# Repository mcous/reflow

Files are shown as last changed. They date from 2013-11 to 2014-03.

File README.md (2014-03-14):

# reflow

Heater controller with thermocouple feedback to control any AC heating appliance. It was originally developed to turn a toaster oven into a solder reflow oven, but it'll control anything that runs on AC and gets hot.

## hardware v0.1

The current board contains an AVR ATMega328P microcontroller, a Sharp S212S01 solid-state relay, and an Analog Devices AD8495 K-type thermocouple amplifier. It has a temperature precision of about 0.5 degrees C and is accurate to about +/- 2 degrees C. It also has start, stop, and mode buttons; a rotary encoder for temperature settings; and a four-digit seven-segment display for showing temperature in C or F. 

The schematic and PCB layout files were created in [KiCad](http://www.kicad-pcb.org) and live the in `pcb` directory.

## firmware v0.1.1

The current firmware has two basic modes: hit and hold. Hit mode takes the temperature up to the set point and then shuts off, while hold mode attempts to hold the temperature at the set-point by turning the heat on when the temperature is below the set point, and off when it's above. This is not PID. It can also display the temperature in either Celsius or Fahrenheit.

The firmware is written in C++ and compiled on OS X using the latest [CrossPack for AVR](http://www.obdev.at/products/crosspack/index.html) and lives in the `firmware` directory. It'll probably compile fine on Linux; no idea about Windows, though.

## operation

* To switch temperature units, hold the set wheel down (it's also a button) until you see an F after the temperature (Fahrenheit) or a number with a decimal point (Celsius)
* To switch modes between hit and hold, press and release the set wheel button; the display will show either "hit" or "hold" for whatever mode has been selected
* To select a set point, turn the set wheel until the display shows your desired temperature
* Press the start button to start heating; the red light will go out and the green light will illuminate
	* In hit mode, once the temperature is hit, the heating will stop and the green light will go out, replaced by the red light
	* In hold mode, the program will not stop unless you tell it to
* Press the stop button to stop heating; the green light will go out and the red light will illuminate
* Whenever the relay is closed (i.e. heat is on) the red LED labeled "HOT" will illuminate

## things this board has been used for

* reflow toaster oven (in hit mode)
* sous vide slow-cooker (in hold mode)

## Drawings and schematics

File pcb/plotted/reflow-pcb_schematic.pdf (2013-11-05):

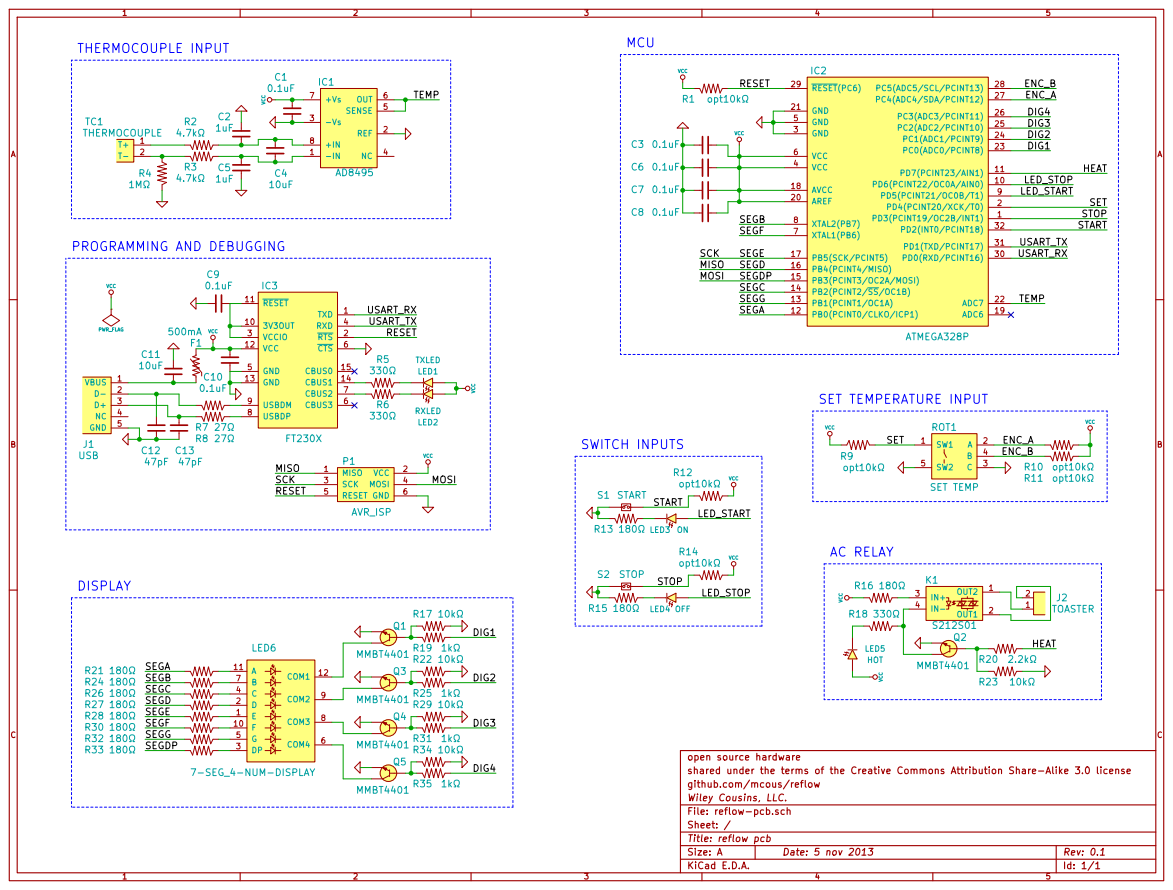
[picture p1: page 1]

LED_STOP
LED_START

MOSI VCC PROGRAMMING AND DEBUGGING

open source hardware
shared under the terms of the Creative Commons Attribution Share-Alike 3.0 license
github.com/mcous/reflow
Wiley Cousins, LLC.
File: reflow-pcb.sch
Sheet: /
Title: reflow pcb

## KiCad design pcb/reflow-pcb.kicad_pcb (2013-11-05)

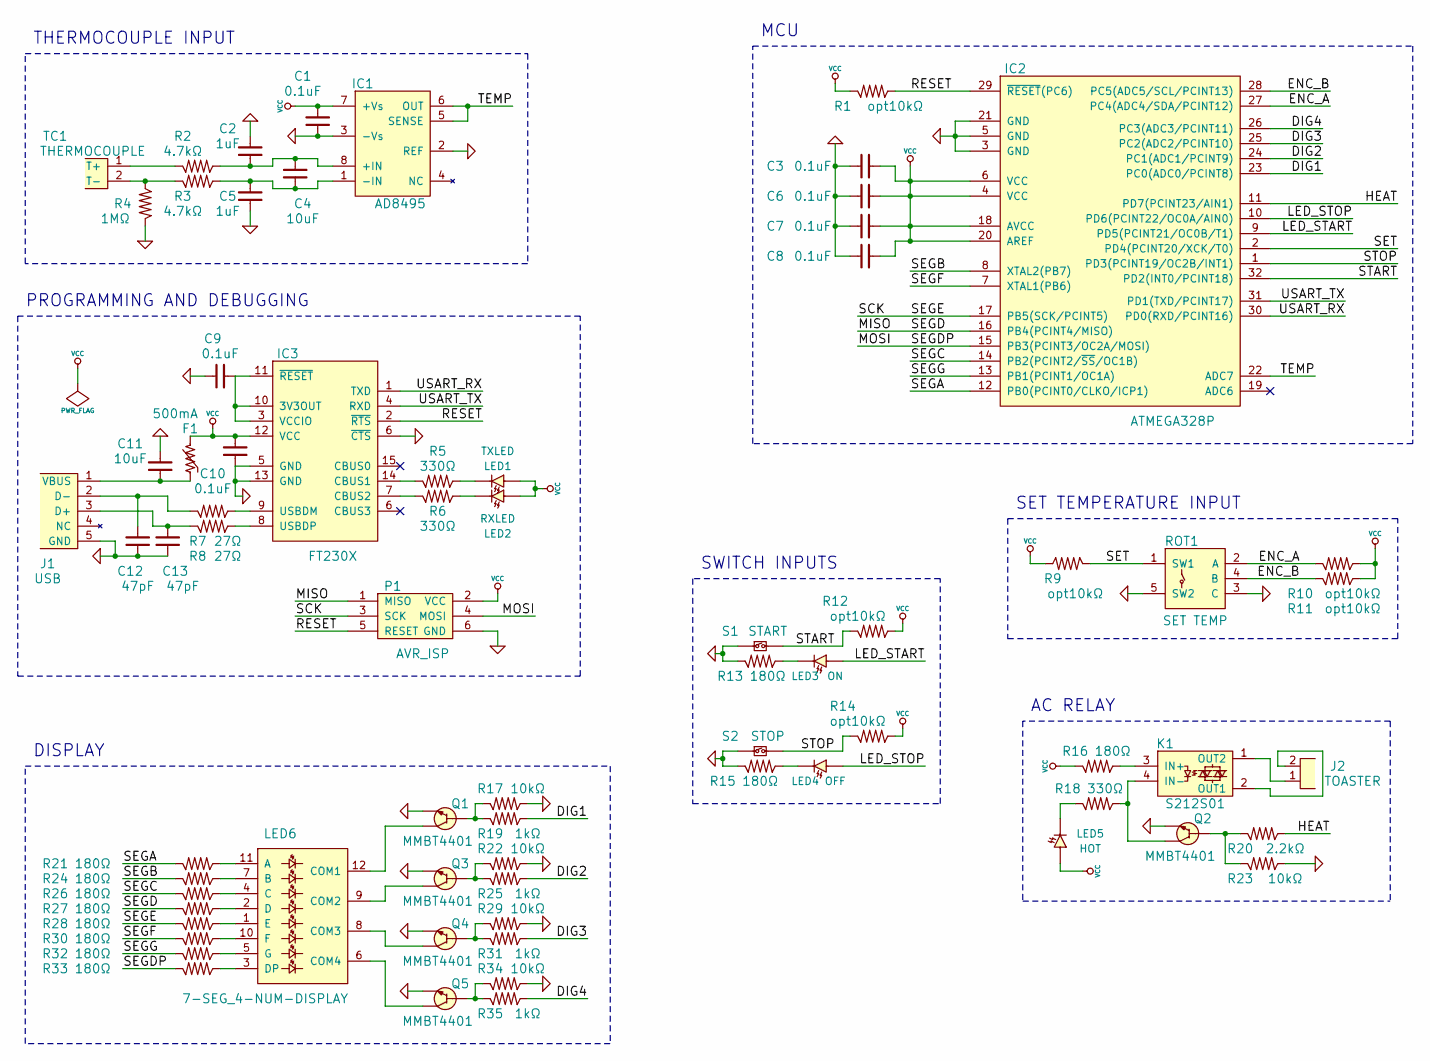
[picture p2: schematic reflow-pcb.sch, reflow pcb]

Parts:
C1, C3, C6, C7, C8, C9, C10: 0.1uF; 0603(1608m)
C2, C5: 1uF; 0603(1608m)
C4, C11: 10uF; 0603(1608m)
C12, C13: 47pF; 0603(1608m)
F1: 500mA; 1206(3216m); Part 0ZCJ0050FF2G
IC1: AD8495; MSOP8; Part AD8495ARMZ
IC2: ATMEGA328P; TQFP32_7mm; Part ATMEGA328P-AU
IC3: FT230X; SSOP16; Part FT230XS-R
J1: USB; MICROUSB_sm; Part 10118192-0001LF
J2: TOASTER; 2-PIN_SCREW-TERM_P200MIL; Part OSTTC022162
K1: S212S01; SHARP_SIP_SSR; Part S212S01F
LED1: TXLED; 0603(1608m)_led
LED2: RXLED; 0603(1608m)_led
LED3: ON; LED-5mm
LED4: OFF; LED-5mm
LED5: HOT; LED-5mm
LED6: 7-SEG_4-NUM-DISPLAY; SF_4-DIGIT_7-SEGMENT_CC; Part COM-11405
P1: AVR_ISP; 2x3-array
Q1, Q2, Q3, Q4, Q5: MMBT4401; SOT23; Part MMBT4401LT1G
R1, R9, R10, R11, R12, R14: opt10kΩ; 0603(1608m)
R2, R3: 4.7kΩ; 0603(1608m)
R4: 1MΩ; 0603(1608m)
R5, R6, R18: 330Ω; 0603(1608m)
R7, R8: 27Ω; 0603(1608m)
R13, R15, R16, R21, R24, R26, R27, R28, R30, R32, R33: 180Ω; 0603(1608m)
R17, R22, R23, R29, R34: 10kΩ; 0603(1608m)
R19, R25, R31, R35: 1kΩ; 0603(1608m)
R20: 2.2kΩ; 0603(1608m)
ROT1: SET TEMP; SF_ROTARY-ENCODER; Part RE130F-41-175F-12P
S1: START; SPST_4-pin-thru
S2: STOP; SPST_4-pin-thru
TC1: THERMOCOUPLE; THERMOCOUPLE_MINI_PCC-SMP; Part PCC-SMP-K

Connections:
/DIG1: IC2.23 (PC0(ADC0/PCINT8)), R19.2
/DIG2: IC2.24 (PC1(ADC1/PCINT9)), R25.2
/DIG3: IC2.25 (PC2(ADC2/PCINT10)), R31.2
/DIG4: IC2.26 (PC3(ADC3/PCINT11)), R35.2
/ENC_A: IC2.27 (PC4(ADC4/SDA/PCINT12)), R10.1, ROT1.2 (A)
/ENC_B: IC2.28 (PC5(ADC5/SCL/PCINT13)), R11.1, ROT1.4 (B)
/HEAT: IC2.11 (PD7(PCINT23/AIN1)), R20.2
/LED_START: IC2.9 (PD5(PCINT21/OC0B/T1)), LED3.2 (A)
/LED_STOP: IC2.10 (PD6(PCINT22/OC0A/AIN0)), LED4.2 (A)
/MISO: IC2.16 (PB4(PCINT4/MISO)), P1.1 (MISO), R27.1
/MOSI: IC2.15 (PB3(PCINT3/OC2A/MOSI)), P1.4 (MOSI), R33.1
/RESET: IC2.29 (~RESET~(PC6)), IC3.2 (~RTS~), P1.5 (RESET), R1.2
/SCK: IC2.17 (PB5(SCK/PCINT5)), P1.3 (SCK), R28.1
/SEGA: IC2.12 (PB0(PCINT0/CLKO/ICP1)), R21.1
/SEGB: IC2.8 (XTAL2(PB7)), R24.1
/SEGC: IC2.14 (PB2(PCINT2/~SS~/OC1B)), R26.1
/SEGF: IC2.7 (XTAL1(PB6)), R30.1
/SEGG: IC2.13 (PB1(PCINT1/OC1A)), R32.1
/SET: IC2.2 (PD4(PCINT20/XCK/T0)), R9.1, ROT1.1 (SW1)
/START: IC2.32 (PD2(INT0/PCINT18)), R12.1, S1.2
/STOP: IC2.1 (PD3(PCINT19/OC2B/INT1)), R14.1, S2.2
/TEMP: IC1.5 (SENSE), IC1.6 (OUT), IC2.22 (ADC7)
/USART_RX: IC2.30 (PD0(RXD/PCINT16)), IC3.1 (TXD)
/USART_TX: IC2.31 (PD1(TXD/PCINT17)), IC3.4 (RXD)
GND: C1.1, C2.2, C3.1, C5.1, C6.1, C7.1, C8.1, C9.1, C10.1, C11.2, C12.1, C13.1, IC1.2 (REF), IC1.3 (-Vs), IC2.3 (GND), IC2.5 (GND), IC2.21 (GND), IC3.5 (GND), IC3.6 (CBUS3), IC3.13 (GND), J1.5 (GND), P1.6 (GND), Q1.2 (E), Q2.2 (E), Q3.2 (E), Q4.2 (E), Q5.2 (E), R4.1, R13.1, R15.1, R17.2, R22.2, R23.2, R29.2, R34.2, ROT1.3 (C), ROT1.5 (SW2), S1.1, S2.1; also elsewhere on the board
unnamed: LED6.11 (A), R21.2
unnamed: LED3.1 (C), R13.2
unnamed: LED4.1 (C), R15.2
unnamed: LED6.7 (B), R24.2
unnamed: LED6.4 (C), R26.2
unnamed: LED6.2 (D), R27.2
unnamed: LED6.1 (E), R28.2
unnamed: LED6.10 (F), R30.2
unnamed: LED6.5 (G), R32.2
unnamed: LED6.3 (DP), R33.2
unnamed: Q1.1 (B), R17.1, R19.1
unnamed: K1.3 (IN+), R16.2
unnamed: Q4.1 (B), R29.1, R31.1
unnamed: Q5.1 (B), R34.1, R35.1
unnamed: LED6.12 (COM1), Q1.3 (C)
unnamed: LED6.9 (COM2), Q3.3 (C)
unnamed: Q3.1 (B), R22.1, R25.1
unnamed: IC3.14 (CBUS1), R5.1
unnamed: IC3.7 (CBUS2), R6.1
unnamed: LED2.1 (C), R6.2
unnamed: IC3.8 (USBDP), R8.2
unnamed: C13.2, J1.3 (D+), R8.1
unnamed: LED1.1 (C), R5.2
unnamed: R2.1, TC1.1 (T+)
unnamed: K1.4 (IN-), Q2.3 (C), R18.2
unnamed: IC3.9 (USBDM), R7.2
unnamed: C9.2, IC3.3 (VCCIO), IC3.10 (3V3OUT), IC3.11 (~RESET~)
unnamed: J2.2, K1.2 (OUT1)
unnamed: LED5.1 (C), R18.1
unnamed: J2.1, K1.1 (OUT2)
unnamed: C12.2, J1.2 (D-), R7.1
unnamed: Q2.1 (B), R20.1, R23.1
unnamed: LED6.8 (COM3), Q4.3 (C)
unnamed: LED6.6 (COM4), Q5.3 (C)
unnamed: C2.1, C4.2, IC1.8 (+IN), R2.2
unnamed: R3.1, R4.2, TC1.2 (T-)
unnamed: C4.1, C5.2, IC1.1 (-IN), R3.2
unnamed: C11.1, F1.1, J1.1 (VBUS)
VCC: C1.2, C3.2, C6.2, C7.2, C8.2, C10.2, F1.2, IC1.7 (+Vs), IC2.4 (VCC), IC2.6 (VCC), IC2.18 (AVCC), IC2.20 (AREF), IC3.12 (VCC), LED1.2 (A), LED2.2 (A), LED5.2 (A), P1.2 (VCC), R1.1, R9.2, R10.2, R11.2, R12.2, R14.2, R16.1

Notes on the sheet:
SWITCH INPUTS
SET TEMPERATURE INPUT
DISPLAY
AC RELAY
THERMOCOUPLE INPUT
PROGRAMMING AND DEBUGGING
MCU

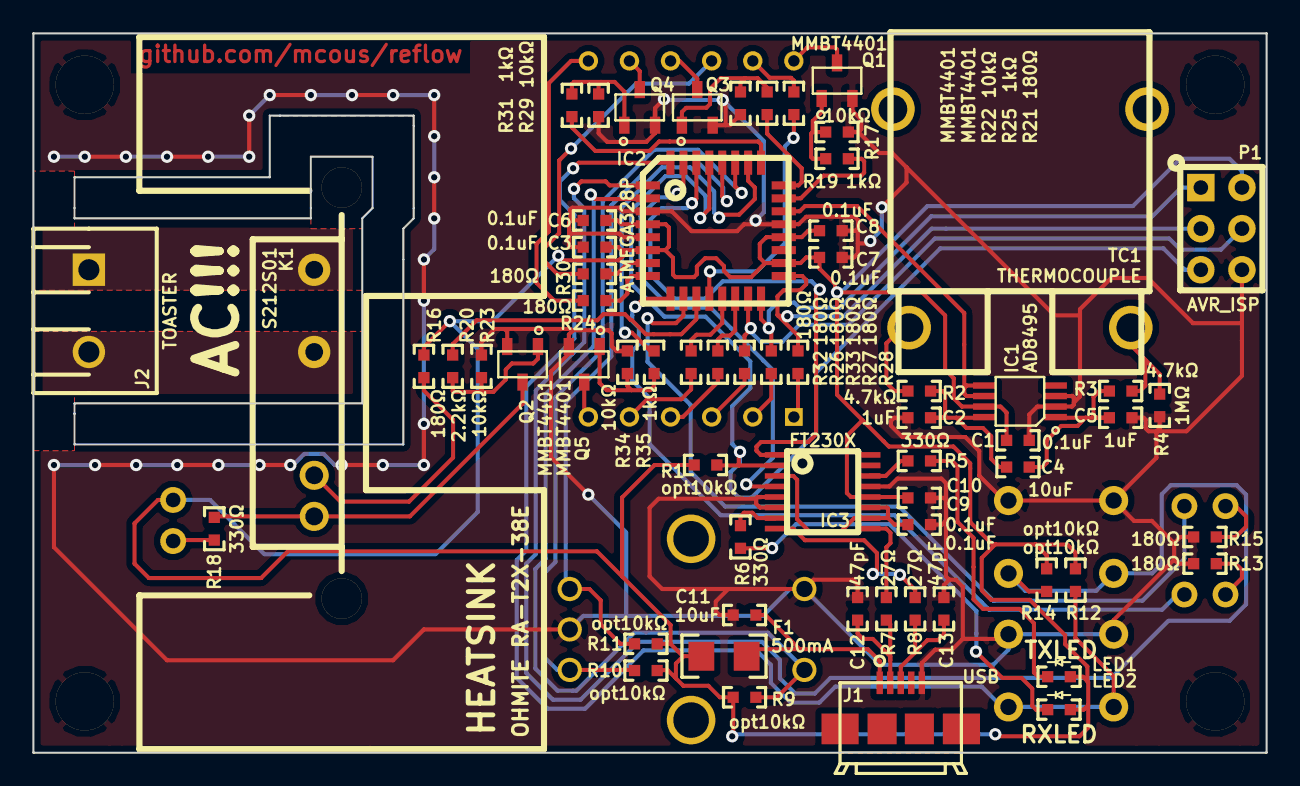
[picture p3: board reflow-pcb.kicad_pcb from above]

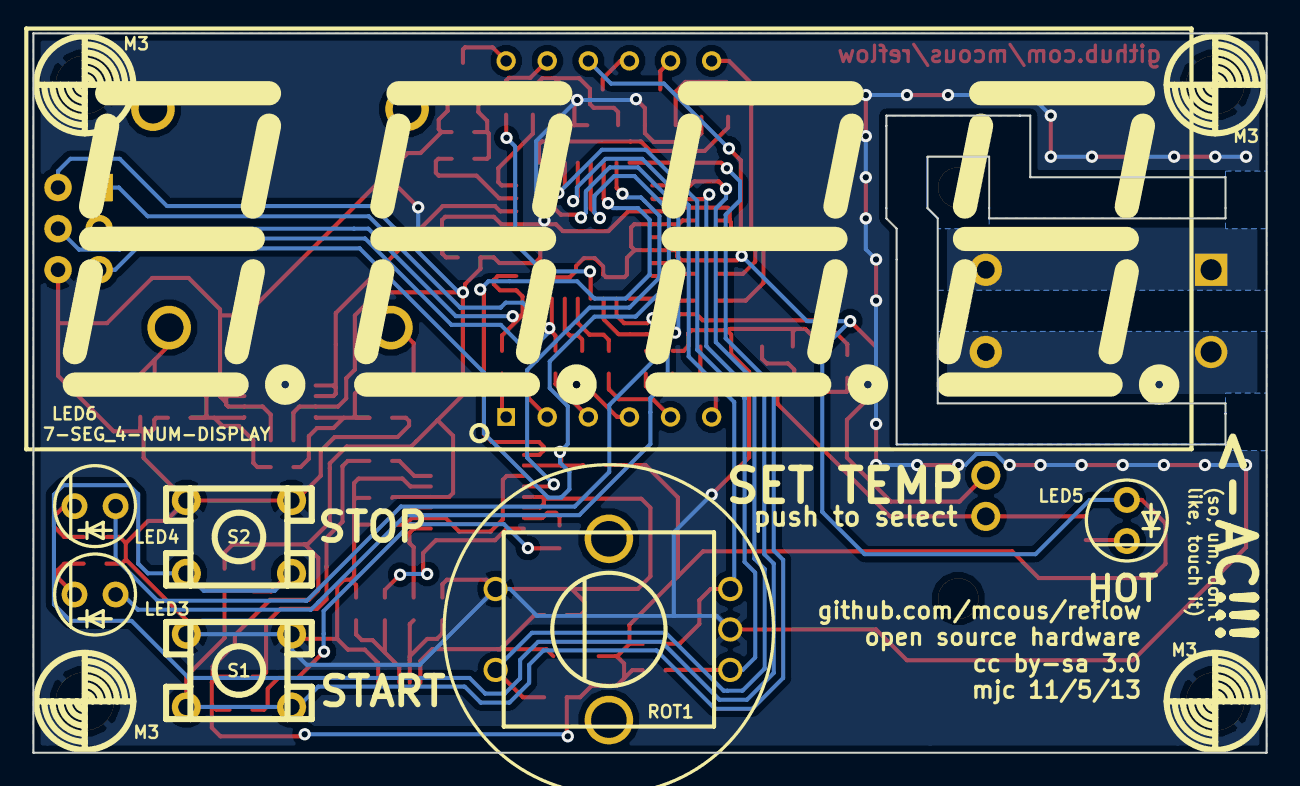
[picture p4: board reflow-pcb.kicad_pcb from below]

Board: 2 copper layers, 76.2 x 44.5 mm, 75 parts (11 on the bottom side), 64 nets.

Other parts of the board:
M3, M3#2, M3#3, M3#4: VAL**; M3

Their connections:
GND: M3.1, M3#2.1, M3#3.1, M3#4.1; also elsewhere on the board

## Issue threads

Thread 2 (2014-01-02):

FTDI RTS signal should go through a capacitor

mcous, 2014-01-02:
RTS line should go through a capacitor to pulse rather than hold AVR reset line.

Closed 2021-04-23.

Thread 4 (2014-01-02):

Need an LDO onboard for a proper AREF

mcous, 2014-01-02:
5V from USB is not an appropriate analog reference voltage as it is not going to be 5V at AREF and there's not a really robust way of measuring it short of using a volt meter and hard-coding the value into the firmware. That's kinda iffy, though. Put a 3.3V LDO on board and everyone's happy.

Closed 2021-04-23.

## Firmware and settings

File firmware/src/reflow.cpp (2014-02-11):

// reflow
// Copyright 2013 by Wiley Cousins, LLC.
// shared under the terms of the MIT License
//
// file: reflow.cpp
// description: application file for the reflow oven controller

#include <avr/io.h>
#include <avr/interrupt.h>
#include <util/atomic.h>
#include <util/delay.h>

#include "reflow.h"
#include "display.h"
#include "buttons.h"
#include "celsius.h"

// macro for event checking
#define event(T, M) ((T & M) == M)

// pin change ISR for rotary encoder
ISR(ENCODER_PCINT_vect) {
  e.handleChange();
}

// applicaiton event timer
ISR(REFLOW_EVENT_vect) {
  // set the flags
  // display refresh
  if (event(eventTimer, REFLOW_DISPLAY_EVENT)) {
    eventFlags |= REFLOW_DISPLAY_FLAG;
  }
  // button polling
  if (event(eventTimer, REFLOW_BUTTON_EVENT)) {
    eventFlags |= REFLOW_BUTTON_FLAG; 
  }
  // encoder reading
  if (event(eventTimer, REFLOW_ENCODER_EVENT)) {
    eventFlags |= REFLOW_ENCODER_FLAG;
  }
  // temperature reading
  if (event(eventTimer, REFLOW_THERMO_EVENT)) {
    eventFlags |= REFLOW_THERMO_FLAG;
  }

  // increment the counter and overflow if necessary
  eventTimer = (eventTimer < REFLOW_EVENT_MAX) ? eventTimer+1 : 0; 
}

// application main method
int main(void) {
  // disable global interrupts for setting stuff
  cli();

  // ISR volatiles
  // should already be 0 but hey safety first
  adcRead = 0;
  eventTimer = 0;
  eventFlags = 0;

  // get the display ready
  Display disp;
  disp.init();
  // get the buttons and encoder input ready
  Buttons b;
  b.init();
  e.init();
  uint8_t encoderCount = MODE_SET_DISPLAY_COUNT;
  uint8_t buttonCount  = MODE_SET_MODE_COUNT;
  // initialize the indicator LEDs
  initLeds();

  // temperature
  initThermo();
  bool targetHit = false;
  Celsius temp;
  Celsius target;
  target.set(200);
  uint8_t tempUnits = TEMP_UNIT_C;

  // text buffer for temperature display
  char d[7];
  uint8_t dLen = temp.toString(d);
  char s[7];
  uint8_t sLen = target.toString(s);

  // operating mode
  uint8_t mode = MODE_OFF | MODE_HIT;
  LED_PORT = (LED_PORT & ~LED_MASK) | LED_STOP;

  // enable the event timer
  enableEventTimer();

  // enable global interrupts
  sei();

  // sideways eight loop
  for (;;) {
    // take care of any events
    // display refresh
    if (eventFlags & REFLOW_DISPLAY_FLAG) {
      // refresh that shit yo
      disp.refresh();
      // clear the flag
      eventFlags &= ~REFLOW_DISPLAY_FLAG;
    }
    // button polling
    if (eventFlags & REFLOW_BUTTON_FLAG) {
      // poll that shit yo
      b.handleTimer();
      // handle buttons
      uint8_t buttons;
      //  button presses
      if (b.getHold(&buttons)) {
        // if set switch is held, switch units
        if (buttons == BUTTON_SET) {
          tempUnits ^= TEMP_UNIT_F;
        } 
      }
      else if (b.getPress(&buttons)) {
        if (buttons == BUTTON_START) {
          mode |= MODE_ON;
          targetHit = false;
        }
        else if (buttons == BUTTON_STOP) {
          mode &= ~MODE_ON;
          HEAT_PORT &= ~HEAT_PIN;
        }
        else if (buttons == BUTTON_SET) {
          buttonCount = 0;
          mode ^= (MODE_HIT | MODE_HOLD);
        }
      }
      // increment counter
      if (buttonCount < MODE_SET_MODE_COUNT) {
        buttonCount++;
      }
      // clear the flag
      eventFlags &= ~REFLOW_BUTTON_FLAG;
    }
    // encoder reading
    if (eventFlags & REFLOW_ENCODER_FLAG) {
      // read that shit yo
      int8_t enc = e.getChange();
      if (enc) {
        encoderCount=0;
        // change target based on encoder speed
        // slower = less increments
        if (enc == -1) {
          target--;
          target--;
        }
        else if (enc == 1) {
          target++;
          target++;
        }
        else if (enc == -2) {
          target -= 1;
        }
        else if (enc == 2) {
          target += 1;
        }
        else if (enc == -3) {
          target -= 10;
        }
        else if (enc == 3) {
          target += 10;
        }
        else if (enc < 0) {
          target -= 20;
        }
        else {
          target += 20;
        }
        // underflow protection
        if (target < 0) {
          target.set(0);
        }
        sLen = target.toString(tempUnits, s);
      }
      // increment counter
      if (encoderCount < MODE_SET_DISPLAY_COUNT) {
        encoderCount++;
      }
      // clear the flag
      eventFlags &= ~REFLOW_ENCODER_FLAG;
    }
    // thermometer reading
    if (eventFlags & REFLOW_THERMO_FLAG) {
      // measure that shit yo
      // take 4 ADC samples and divide by 2 to oversample to 11-bit precision
      // then, convert 11-bit number to 4x degrees C
      // steps combined for efficiency
      uint32_t c = 0;
      for (uint8_t i=4; i>0; i--) {
        // start an ADC conversion
        ADCSRA |= (1<<ADSC);
        // wait for conversion to complete
        while (ADCSRA & (1<<ADSC));
        c += ( ADCL | (ADCH << 8) );
      }
      c *= 25 * VREF;
      c >>= 7;
      temp.setScaled((int16_t)(c), TEMP_POWER);
      dLen = temp.toString(tempUnits, d);
      // clear the flag
      eventFlags &= ~REFLOW_THERMO_FLAG;
    }

    

    // check for open thermocouple
    if (temp > 500) {
      // write error flag
      mode |= MODE_ERR;
    }
    // else thermo data is good
    else {
      // clear error flag
      mode &= ~MODE_ERR;
      // check if we're displaying the set temp
      if (encoderCount < MODE_SET_DISPLAY_COUNT) {
        mode |= MODE_SET;
      }
      else if (buttonCount < MODE_SET_MODE_COUNT) {
        mode |= MODE_SHOW;
      }
      else {
        mode &= ~(MODE_SET | MODE_SHOW);
        if (mode & MODE_ON) {
          if (temp < target) {
            HEAT_PORT |= HEAT_PIN;
          }
          else {
            HEAT_PORT &= ~HEAT_PIN;
            if (mode & MODE_HIT) {
              mode &= ~MODE_ON;
              targetHit = true;
            }
          }
        }
      }
    }

    // set the display and status LEDs
    if (mode & MODE_ON) {
      LED_PORT = (LED_PORT & ~LED_MASK) | LED_START;
    }
    else {
      LED_PORT = (LED_PORT & ~LED_MASK) | LED_STOP;
    }
    // error is first priority, then set, then value
    if (mode & MODE_ERR) {
      char e[5] = {'e', 'r', 'r', '0', '\0'};
      disp.set(e, 4);
    }
    else if (mode & MODE_SET) {
      disp.set(s, sLen);
    }
    else if (mode & MODE_SHOW) {
      if (mode & MODE_HIT) {
        char e[4] = {'h', 'i', 't', '\0'};
        disp.set(e, 3); 
      }
      else {
        char e[5] = {'h', 'o', 'l', 'd', '\0'};
        disp.set(e, 4); 
      }
    }
    else {
      disp.set(d, dLen);
    }
  }

  // DEEP THOUGHT
  return 42;
}

// event timer
void enableEventTimer(void) {
  // enable timer 1 to fire at 512Hz
  // CTC mode, no prescaler, OCR1A = 15625
  TCCR1A = 0;
  TCCR1B = ( (1<<WGM12) | (1<<CS10) );
  TCCR1C = 0;
  OCR1A = 15625;
  // enable the compare interrupt
  TIMSK1 = (1<<OCIE1A);
}

void initLeds(void) {
  // set pins as outputs
  DDR(LED_PORT) |= LED_MASK;
  // set pins to low (off)
  LED_PORT &= ~LED_MASK;
}

void initHeat(void) {
  // set heater to output
  DDR(HEAT_PORT) |= HEAT_PIN;
  // set low (off)
  HEAT_PORT &= ~HEAT_PIN;
}

// intialize thermocouple reading
void initThermo(void) {
  // set up ADC on ADC7 with VREF as the reference voltage
  ADMUX = 7;
  // slow things down to 8 MHz / 64 = 125 kHz
  ADCSRA = ( (1<<ADPS2) | (1<<ADPS1) );
  // enable ADC, do a reading, and toss it
  ADCSRA |= ( (1<<ADEN) | (1<<ADSC) );
  // wait for conversion to complete
  while (ADCSRA & (1<<ADSC));
  // read the value;
  uint16_t read = ADCL | (ADCH << 8);
  (void) read;
}

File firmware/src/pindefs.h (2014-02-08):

// reflow
// Copyright 2013 by Wiley Cousins, LLC.
// shared under the terms of the MIT License
//
// file: pindefs.h
// description: pin definitions file for the reflow oven controller

#ifndef REFLOW_PINDEFS_H
#define REFLOW_PINDEFS_H

// include for AVR register addresses and interrupt vectors
#include <avr/io.h>

// DDR and PIN from port register macros
#define DDR(port) (*(&port-1))
#define PIN(port) (*(&port-2))

// display ports
#define DISPLAY_DIG_PORT  PORTC
#define DISPLAY_DIG_MASK  0x0F
#define DISPLAY_SEG_PORT  PORTB
#define DISPLAY_SEG_MASK  0xFF
// display segment pins
#define DISPLAY_SEG_A   (1<<0)
#define DISPLAY_SEG_B   (1<<7)
#define DISPLAY_SEG_C   (1<<2)
#define DISPLAY_SEG_D   (1<<4)
#define DISPLAY_SEG_E   (1<<5)
#define DISPLAY_SEG_F   (1<<6)
#define DISPLAY_SEG_G   (1<<1)
#define DISPLAY_SEG_DP  (1<<3)

// pushbutton port
#define BUTTON_PORT   PORTD
#define BUTTON_SET    (1<<4)
#define BUTTON_START  (1<<2)
#define BUTTON_STOP   (1<<3)
#define BUTTON_MASK   ( BUTTON_STOP | BUTTON_START | BUTTON_SET )
// pushbutton polling / debounce timer
#define BUTTON_TIMER_OVF_vect  TIMER2_OVF_vect

// encoder port
#define ENCODER_PORT   PORTC
#define ENCODER_A      (1<<4)
#define ENCODER_B      (1<<5)
#define ENCODER_MASK   ( ENCODER_B | ENCODER_A )
#define ENCODER_SHIFT  4
// encoder pin change
#define ENCODER_PCIE        (1<<PCIE1)
#define ENCODER_PCMSK       PCMSK1
#define ENCODER_PCINT_vect  PCINT1_vect

// mode indicator LEDs
#define LED_PORT   PORTD
#define LED_STOP   (1<<6)
#define LED_START  (1<<5)
#define LED_MASK   (LED_START | LED_STOP)

// heater
#define HEAT_PORT  PORTD
#define HEAT_PIN   (1<<7)

// temperature reading
#define TEMP_ADC  (1<<7)

#endif

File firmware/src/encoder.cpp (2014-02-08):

// reflow
// Copyright 2013 by Wiley Cousins, LLC.
// shared under the terms of the MIT License
//
// file: encoder.cpp
// description: class for rotary encoder input

#include "encoder.h"
#include "pindefs.h"

// contructor
Encoder::Encoder(void) {
  loc = 0;
  tick = 0;
  state = 0;
}

// encoder transition lookup table
const int8_t Encoder::trans[] PROGMEM = {
  0, 1, -1, 0, -1, 0, 0, 1, 1, 0, 0, -1, 0, -1, 1, 0
};

// initialization of pins and interrupts
void Encoder::init(void) {
  initPins();
  state = getState();
  initInt();
}
 
// handle the pin change interrupt (preferably with aplomb) 
void Encoder::handleChange(void) {
  // shift the previous state over and pull in the new state
  state = (((state<<2) | getState()) & 0x0F);
  // increment or decrement the location with the lookup table
  tick += pgm_read_byte(&(trans[state]));
  if (tick > 3) {
    tick = 0;
    loc++;
  }
  else if (tick < -3) {
    tick = 0;
    loc--;
  }
}

// get rotation since last check
// clockwise = positive, counter-clockwise = negative
int8_t Encoder::getChange(void) {
  int8_t ret = loc;
  loc = 0;
  return ret;
}

// get encoder state
// returns 0000 00AB
uint8_t Encoder::getState(void) {
  // mask the encoder pins and shift for processing
  return ((PIN(ENCODER_PORT) & ENCODER_MASK) >> ENCODER_SHIFT);
}

// initialize pins and pullups
void Encoder::initPins(void) {
  // set pins to input
  DDR(ENCODER_PORT) &= ~ENCODER_MASK;
  // enable pullups
  ENCODER_PORT |= ENCODER_MASK;
}

// initialize pin change interrupts
void Encoder::initInt(void) {
  // set up pin change interrupt on the pins
  ENCODER_PCMSK |= ENCODER_MASK;
  // enable the interrupt
  PCICR |= ENCODER_PCIE;
}

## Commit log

2013-11-02 starting kicad project
2013-11-02 starting schematic
    [relow-pcb.sch]
2013-11-03 thermocouple circuit set up
    [relow-pcb.sch]
2013-11-03 realy circuit done
    [relow-pcb.sch]
2013-11-03 added rotary encoder
    [relow-pcb.sch]
2013-11-03 going to bed
2013-11-03 added a display
    [relow-pcb.sch]
2013-11-03 initial pass at schematic done
    [relow-pcb.sch]
2013-11-04 I lied. Adding a FTDI USB to USART
    [relow-pcb.sch]
2013-11-04 might actually be done with this schematic
    [relow-pcb.sch]
2013-11-04 footprint assignment almost done. going to bed
    [relow-pcb.sch]
2013-11-05 working on the board
    [relow-pcb.kicad_pcb, relow-pcb.sch]
2013-11-05 components placed. starting traces
    [relow-pcb.kicad_pcb, relow-pcb.sch]
2013-11-05 laying traces like it's my job
    [relow-pcb.kicad_pcb]
2013-11-05 layout done. ready to order (after triple checking)
    [relow-pcb.kicad_pcb, relow-pcb.sch]
2013-11-05 minor trace changes and gerbers plotted
    [relow-pcb-B_Cu.gbl, relow-pcb-B_Mask.gbs, relow-pcb-B_SilkS.gbo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]
2013-11-05 going to bed again
    [relow-pcb.kicad_pcb, relow-pcb.sch]
2013-11-05 USB caps should be 47pF, not 47nF
    [relow-pcb.kicad_pcb, relow-pcb.sch]
2013-11-05 how about i spell "reflow" correctly?
    [reflow-pcb-B_Cu.gbl, reflow-pcb-B_Mask.gbs, reflow-pcb-B_SilkS.gbo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]
2013-11-05 adding schematic plot to rev control
2013-11-05 moving gerber files to gerber folder
    [reflow-pcb-B_Cu.gbl, reflow-pcb-B_Mask.gbs, reflow-pcb-B_SilkS.gbo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]
2013-11-05 this version sent to fabrication
    [reflow-pcb.sch]
2013-11-21 can't get olimex isp to work, so switching to Arduino as ISP
2013-11-21 button inputs are working
2013-11-21 renamed input class to buttons
2013-11-21 adding files for rotary encoder class
2013-11-21 ok actually going to bed
2014-01-02 this works well enough to toast boards
2014-02-04 redid the ADC to temperature math to be better
2014-02-04 changed buttons to polling only
2014-02-04 moved encoder lookup table to program memory
2014-02-05 adding a unit testing framework for non-hardware classes
2014-02-05 starting a new clas for the temperature
2014-02-06 main app now uses celsius class instead of floats for temperature
2014-02-08 pure polling buttons work
2014-02-10 basic events framework seems to operate fairly well
2014-02-10 working on improving adc
2014-02-11 added temp display in F, automatic display of target temp when encoder is turned, and oversampled the ADC to 11-bits of precision
2014-02-11 improved encoder responsiveness and speed

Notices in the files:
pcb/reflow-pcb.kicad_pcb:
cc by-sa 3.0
